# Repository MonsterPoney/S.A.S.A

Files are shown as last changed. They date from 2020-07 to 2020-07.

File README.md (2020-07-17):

# Projet S.A.S.A (Système Autonome de Stabilisation Active)
## Description
Le projet S.A.S.A. (Système Autonome de Stabilisation Active) a pour but de rendre les fusées amateures actuelles plus permissive en leurs appliquant une autonomie.
On passerait donc d’un système passif purement basé sur l’aérodynamique et dont l’allumage du/des moteur(s) scellerait quelconque action pour modifier la trajectoire a un système ‘intelligent’ pouvant effectuer des actions durant le vol permettant de stabiliser la trajectoire de la fusée.

## Les actions
Une stabilisation active sera amenée grâce à des empennages amovibles et un moteur à propulsion vectorielle.
Un seul moteur ne pouvant effectuer de correction de roulis, c’est donc les empennages qui auront ce rôle et le moteur effectuera les corrections de tangage et de lacet.

## Platine d'essai
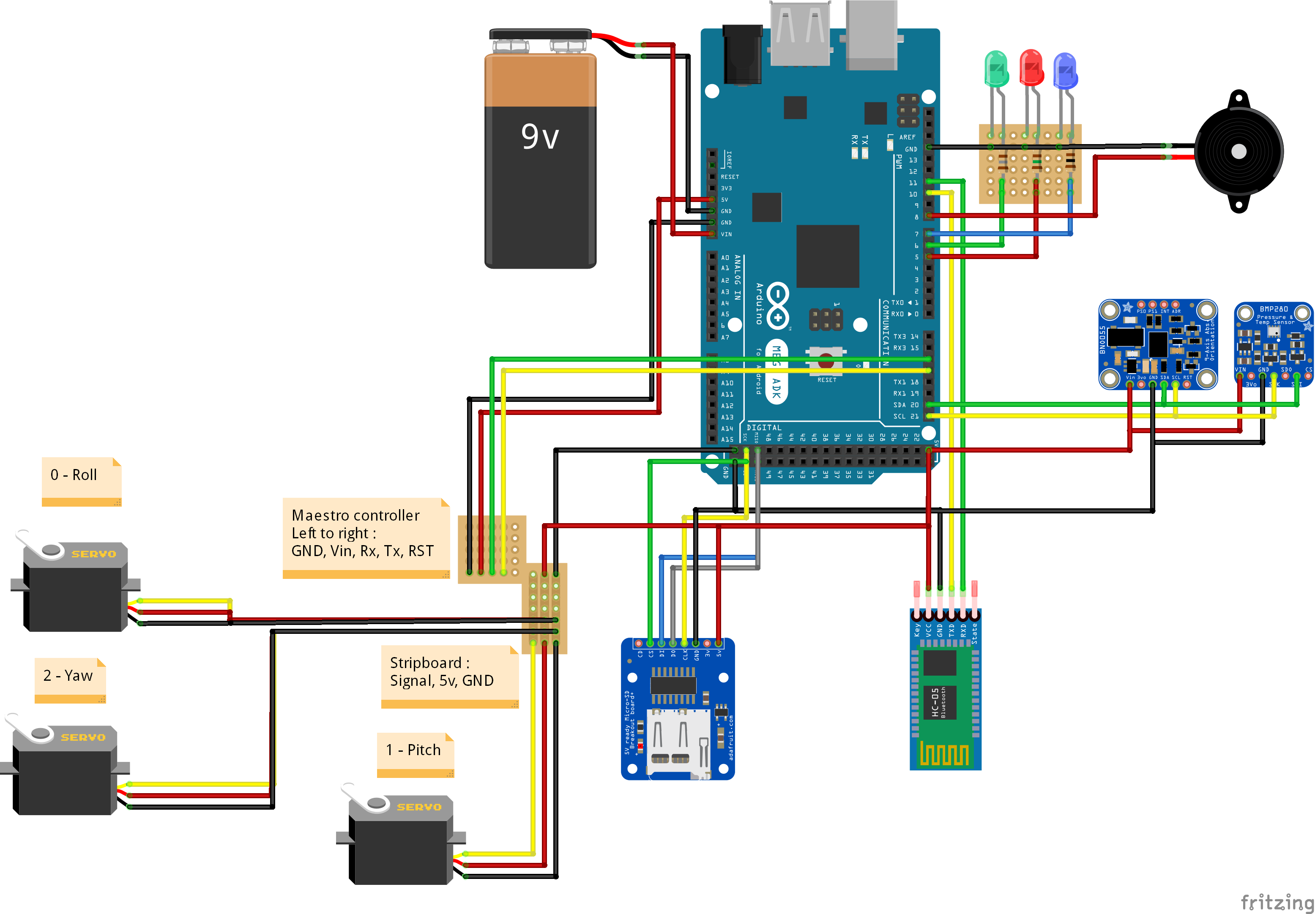
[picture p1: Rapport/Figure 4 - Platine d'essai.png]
alt platine d'essai


## Exemple de diagramme de temps
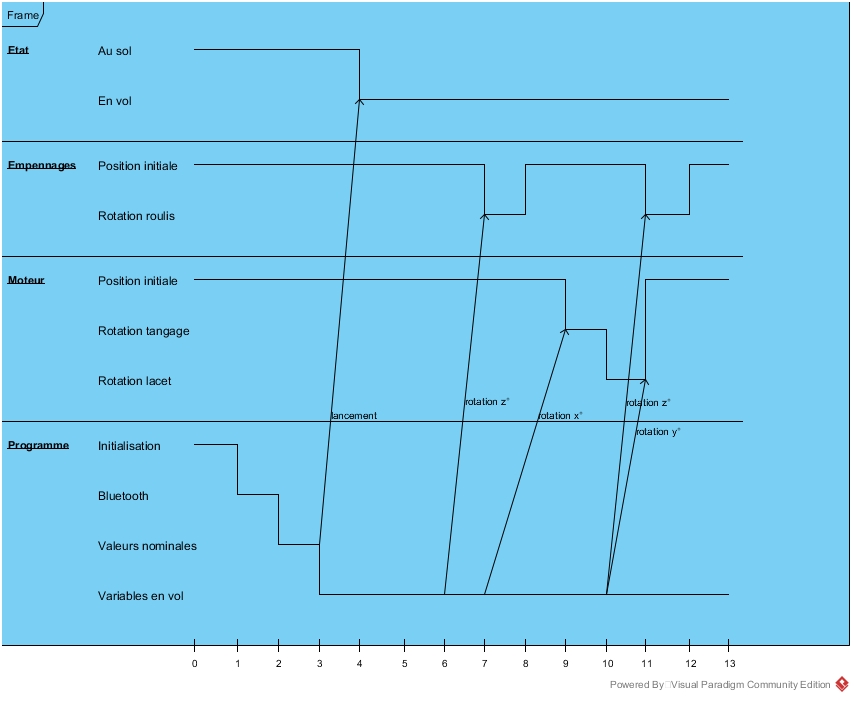
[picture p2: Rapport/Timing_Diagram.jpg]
alt diagramme de temps


## Organigramme de programmation initial
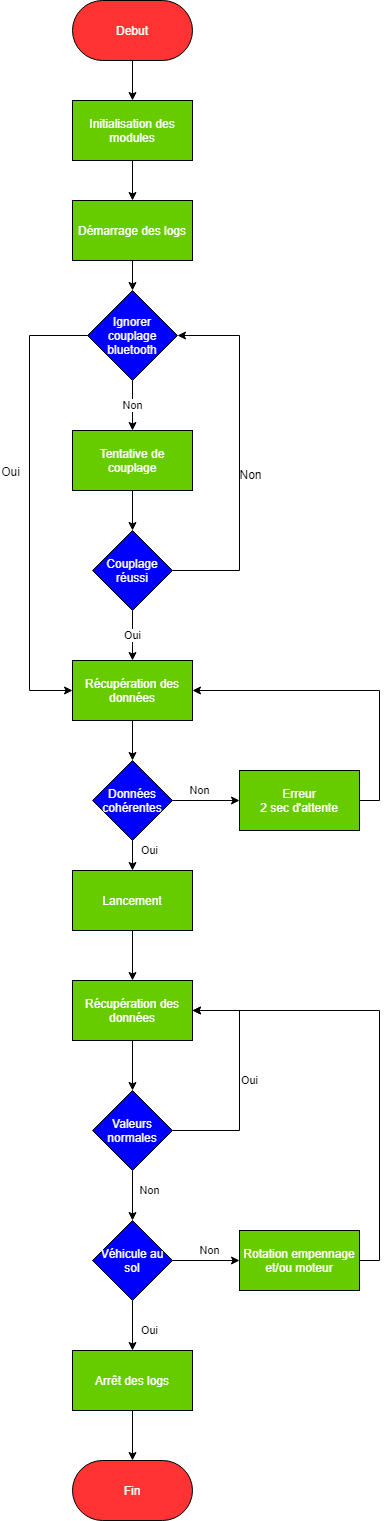
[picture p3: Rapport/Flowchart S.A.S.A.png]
alt Organigramme de programmation


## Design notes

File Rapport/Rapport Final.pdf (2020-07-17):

BOUR Valentin

Projet :
Système Autonome de
Stabilisation Active

# Rapport de projet

Introduction________________________________________________

Le projet S.A.S.A. (Système Autonome de Stabilisation Active) a pour but de rendre les fusées amateures actuelles plus permissive en leurs appliquant une autonomie.

Avec une stabilisation passive, la trajectoire ne peut être que légèrement parabolique ou rectiligne et aucune intervention ne peut être effectué pour modifier celle-ci une fois le ou les moteurs allumé(es).
On passerait donc d’un système passif purement basé sur l’aérodynamique et dont l’allumage du/des moteur(s) scellerait quelconque action pour modifier la trajectoire a un système ‘intelligent’ pouvant effectuer des actions durant le vol permettant de stabiliser la trajectoire de la fusée.

Le système n’utilisera pas de RCS ou d’actionneur gyroscopique à cause du coût et de la masse du dispositif, de plus des actionneurs gyroscopiques peuvent provoquer des vibrations et déstabilisé la fusée.

Les actions du dispositif_____________________________________

Une stabilisation active sera amenée grâce à des empennages amovibles et un moteur à propulsion vectorielle.
Un seul moteur ne pouvant effectuer de correction de roulis, c’est donc les empennages qui auront ce rôle et le moteur effectuera les corrections de tangage et de lacet.
Couplé à un ordinateur de bord, ce système peut alors devenir autonome.
Le système dispose également d’un module Bluetooth, si un appareil est appairé a celui-ci, il recevra les informations de pré-lancement tel que les valeurs de base du 9-DOF.
Le BNO055 (9-DOF) détectera le lancement, il s’en suivra donc l’activation complète du dispositif puis lorsque la phase d’atterrissage sera complète, l’accélération sera nulle, ce qui pourra arrêter le système.

Système Autonome de
Stabilisation Active

Les contraintes_____________________________________________

Le système doit être le plus léger possible afin d’avoir le moins d’impact sur les performances, il doit également être le plus petit possible.
Les mouvements des servos se doivent d’être précis et fluides afin d’avoir le moins de marge d’erreur et ne pas avoir d’accoups.
Aucune intervention humaine doit être nécessaire durant tout le procédé post-lancement.

Matériel___________________________________________________

1 Carte microcontrôleur
3 Servos
1 Contrôleur servos
1 Module bluetooth
1 Module SD
1 Capteur de pression
1 9-DOF

La carte microcontrôleur utilisé est un Arduino Mega 2560, l’utilisation d’une carte nano est possible pour réduire la taille et la masse.
Les servos sont des FS0403 de Feetech.
Le contrôleur servos est un Micro Maestro 6 canaux.
Le module bluetooth est un module HC-05.
Le module SD est une breakout SD avec régulateur 3.3v.
Le capteur de pression est le BMP280 et est utilisé pour obtenir l’altitude. La centrale inertielle 9-DOF est le BNO055.

Recherches________________________________________________

De nombreuses recherches ont été effectués durant l’accomplissement de ce projet à commencer par trouver le matériel nécessaire respectant les contraintes.

De conséquentes recherches sur la stabilité et l’aérodynamisme ont également été effectués, le système exercera son rôle dans un environnement contenant énormément de variables toutes cruciales, le moteur vectoriel et les empennages mobiles sont des acteurs importants et auront donc une incidence importante, ils ne doivent évidemment pas être négligés.

Système Autonome de
Stabilisation Active

Model 3D__________________________________________________

Le model 3D a été d’une grande aide, il a servi de référence pour le prototype et à aider à visualiser la mobilité de certains éléments ainsi que les contraintes mécaniques liés à l’espace.
Ce model a également été utile pour l’impression d’éléments.
Une animation d’assemblage a été réaliser, ce qui permet d’obtenir une perspective différente.
La modélisation a été faite sur Blender, un logiciel libre permettant également de faire de l’animation et du texturage.

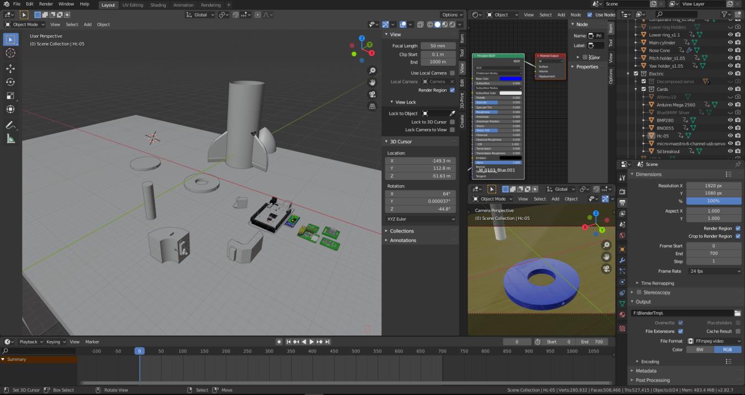
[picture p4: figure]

Figure 1 - Interface Blender

Le fichier compte une vingtaine d’objets constituant le système.

Système Autonome de
Stabilisation Active

Prototypage________________________________________________

Après la finalisation du model 3D, chaque pièce étant destinée à être imprimé doit généralement subir une transformation pour que celle-ci soit imprimable, surtout dans le cas où la pièce en question a été créé dans un logiciel non spécialisé dans la conception par ordinateur.

Les 2 principaux problèmes pouvant survenir :

- Overhangs : Les parties en surplomb, au-dessus d’un vide.
Ils doivent être éviter au maximum mais peuvent être résolu lors du passage dans un slicer en ajoutant des supports. Le temps d’impression sera donc augmenté.
- Non manifold geometry : Géométries ne pouvant exister dans le monde réel (faces à l’intérieur d’un objet, zones avec une épaisseur nulle, sommets ou arêtes déconnectées).

Après quelques essais d’impressions, un prototype en PLA a été réaliser, le slicer utiliser est Cura, il permet de paramétrer et de prévisualiser l’impression.

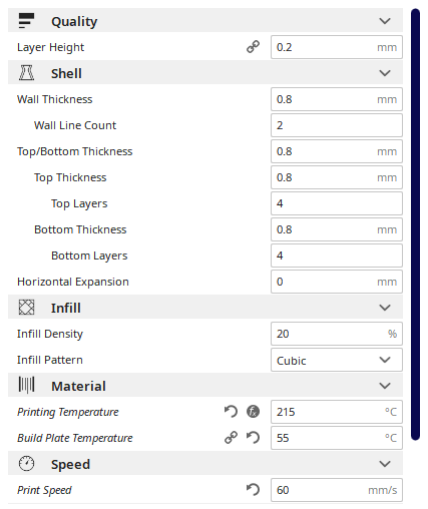
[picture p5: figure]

Figure 2 - Exemple de paramètres

Voici quelques-uns des paramètres les plus importants comme la hauteur de couche, l’épaisseur des parois, le pattern de remplissage ainsi que sa densité, la température et la vitesse d’impression.

Système Autonome de
Stabilisation Active

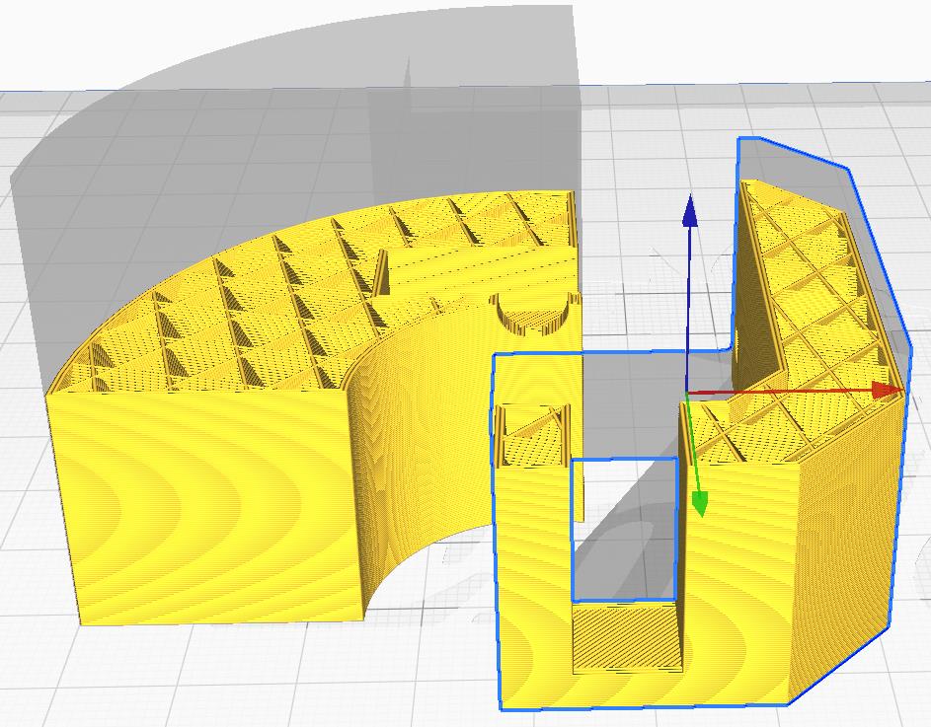
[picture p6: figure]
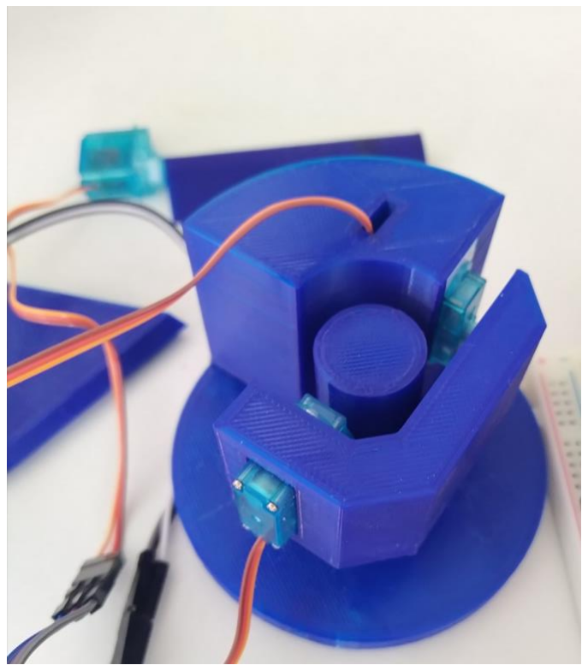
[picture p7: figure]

Figure 4 - Résultat d'impression

Après découpage, le logiciel estime un temps d’impression et une quantité de matériaux utilisé, une prévisualisation du parcours de la buse et également disponible.

Figure 3 - Visualisation du découpage

Système Autonome de
Stabilisation Active

Assemblage électronique____________________________________

Le montage électronique a été réaliser sans trop de difficultés grâce à l’utilisation d’une carte Arduino facilitant grandement la gestion des entrées / sorties du microprocesseur. Possédant déjà un Arduino Mega, celle-ci a été utilisée mais une Nano est suffisante pour ce système et est plus petite et plus légère.
Des ajustements peuvent être réalisés mais aucun changement majeur ne sera effectué. Un schéma du système a été réalisé.

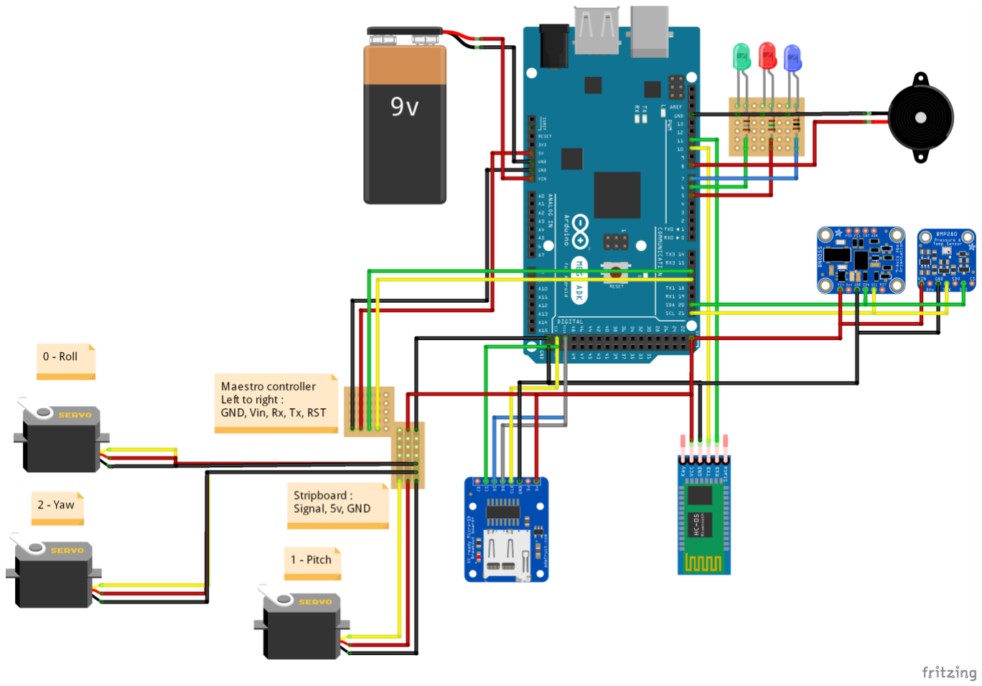
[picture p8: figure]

Figure 5 - Platine d'essai

Système Autonome de
Stabilisation Active

La représentation graphique a été faite sur Fritzing, le contrôleur servos n’étant pas disponible, il a été représenter par deux cartes à matrice et annoté en conséquence. Le module SD est visible en bas à droite des servos, à côté de celui-ci, le module Bluetooth.
A droite de l’écran se trouve le BNO055 et le BMP280.

Programmation_____________________________________________

Un souci matériel a causé un problème de communication avec le contrôleur de servos empêchant donc toute interaction avec ceux-ci, ce problème a été résolu.

Les acquisitions de données du capteur initial ont montré que celui-ci avait besoin d’être calibré pour fonctionner de correctement, la complexité d’utilisation de ce capteur m’a donc freiné, c’est pour cette raison que je l’ai remplacé par deux autres capteurs.

Un module Bluetooth (HC-05) envoie les données de pré-lancement a l’appareil appairé, pour des raisons d’intégrité le système n’est pas pilotable à distance, le module ne traite donc aucunes données et ne réalise que des envoie.

Une carte microSD enregistre constamment l’état du programme et des capteurs, ce qui permet une persistance de données et un traçabilité d’éventuelles erreurs.
Le fichier résultant de cet enregistrement est un simple fichier texte, cependant, sa mise en page permet d’exploiter ce document dans un tableur afin d’en faire une analyse (graphique, calcul etc…).

Les valeurs d’axes fourni par le 9-DOF possèdent une échelle différente des servos, j’effectue donc une conversion afin de les rendre compréhensible par ceux-ci.

Système Autonome de
Stabilisation Active

Simulation_________________________________________________

Les simulateurs ne peuvent pas prendre en compte une stabilisation active, les simulations ont donc été utilisées pour voir l’impact du dispositif sur la fusée. Le principal outil utilisé est OpenRocket, il permet une création et une visualisation en 2D de la fusée.
Des paramètres environnementaux peuvent être spécifiés.

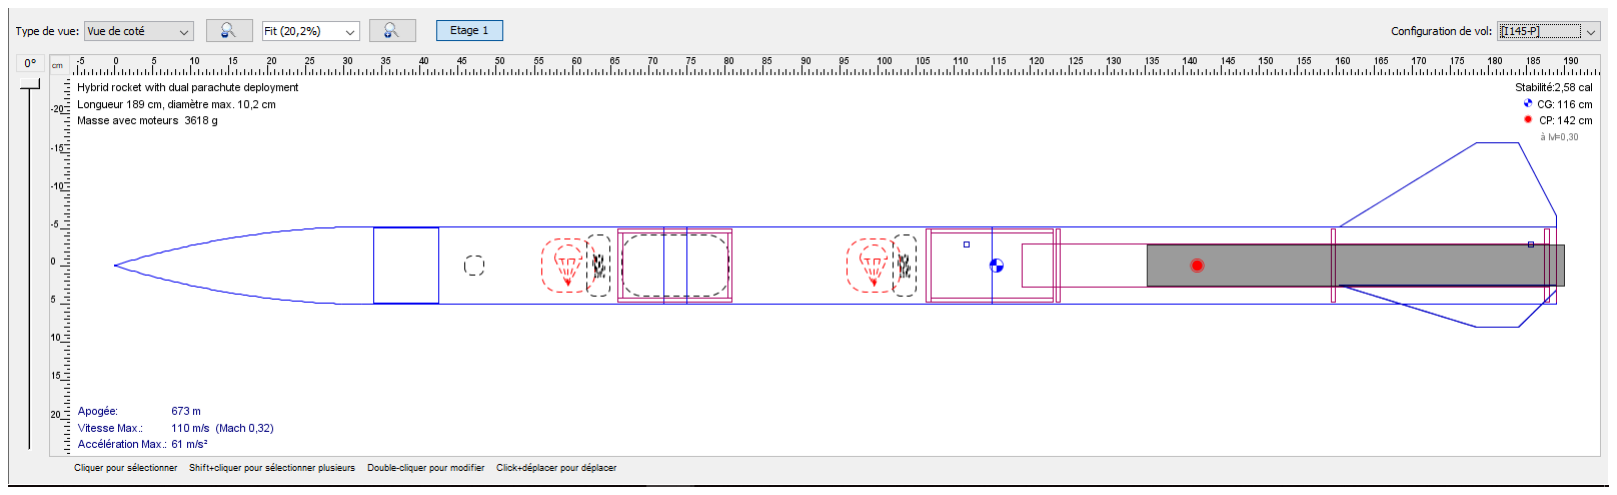
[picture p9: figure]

Figure 6 - Visuel de conception

Deux simulations ont été effectuée :
La première avec la stabilisation passive, donc sans système
La seconde avec la stabilisation active
La différence se traduit par la diminution des turbulences et perturbations et en ajoutant une masse simulant celle du système.

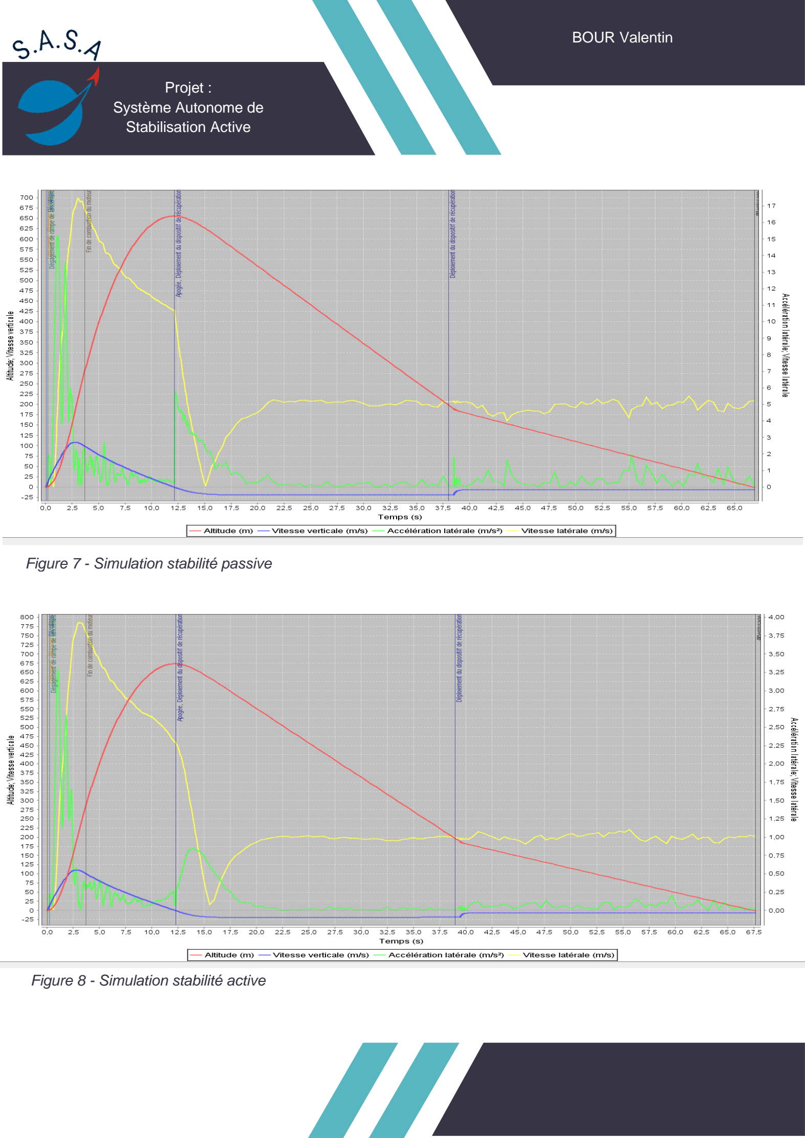
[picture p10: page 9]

Système Autonome de
Stabilisation Active

Figure 7 - Simulation stabilité passive

Figure 8 - Simulation stabilité active

Système Autonome de
Stabilisation Active

Nous pouvons voir que la simulation avec stabilité active a une accélération latérale moindre car le système compense les aléas environnementaux.
De ce fait son altitude max (apogée) est plus grande, 674m contre 657m sur le 1e graphique.
Donc la masse que représente le dispositif est compensée par son action, une différence de 2.58% est visible sur l’apogée.

Ce pourcentage peut sembler dérisoire, en effet, appliqué à une apogée initiale de 10m, le système n’est que peu avantageux.
Cependant, certaines fusées expérimentales tel que la fusée « Elyjia » lancée en 2007 atteignent une altitude supérieure à 1km (1700m dans le cas d’Elyjia).

Code couleur est sonore du système___________________________

- Led bleu, vert et rouge : Standby
- Led bleu, vert, rouge et bip sonore discontinue : Standby post atterrissage / amerrissage
- 2 courts bips sonores : Carte SD non détectée
- Led rouge et 3 longs bips sonores : Erreur critique (BNO055 ou BMP280 non détectée)
- 1 long bip sonore : Acquisition et mise en place des valeurs par défaut terminé

Glossaire__________________________________________________

- Axes aérodynamiques :
- Roulis : Rotation autour de l’axe longitudinale de la fusée
- Tangage : Rotation autour de l’axe latéral
- Lacet : Rotation autour de l’axe vertical
- BMP280 : Capteur de pression / Altimètre
- BNO055 / 9-DOF : 9 Degrees Of Freedom, 3 axes données par 3 capteurs, un gyroscope, un accéléromètre et un magnétomètre.
- RCS : Reaction Control System

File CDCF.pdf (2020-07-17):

BOUR Valentin

Projet :
Système Autonome de
Stabilisation Active
BOUR Valentin | Msc.1

# Cahier des Charges Fonctionnel

Projet S.A.S.A.

Présentation générale du besoin

Situation actuelle
Du fait de leurs courte durée de fonctionnement et de leurs apogée faible, les micro-fusées (propulseur de type A,B et C) ne disposent que d’une stabilisation passive à l’aide d’empennages fixes.

Cependant,les mini-fusées ainsi que les fusées à cluster ou à étages peuvent atteindre une hauteur bien plus élevé et donc un fonctionnement plus long.

Avec une stabilisation passive, la trajectoire ne peut être que légèrement parabolique ou rectiligne et aucune intervention ne peut être effectué pour modifier celle-ci une fois le ou les moteurs allumé(es).

Solutions déjà explorées, exclues
Une solution de RCS (Reaction Control System) est exclu du fait de son coût et de la masse du dispositif.

Les actionneurs gyroscopiques sont exclus à cause de leurs faible efficacité dans l’atmosphère et des vibrations provoquée par ce système qui pourrait avoir l’effet inverse et déstabilisé la fusée.

Résultats et changements attendu

Une stabilisation active peut être amené grâce à des empennages movibles et un moteur à propulsion vectorielle.
Un seul moteur ne pouvant effectuer de correction de roulis, c’est donc les empennages qui auront ce rôle et le moteur effectuera les corrections de tangage et de lacet.
Couplé à un ordinateur de bord, ce système peut alors devenir autonome.

Le système peut également être doté d’un module bluetooth afin d’envoyer des informations pré lancement à une application Android pour contrôler la cohérence des valeurs avant le lancement.

Système Autonome de
Stabilisation Active

Expression détaillée du besoin

Phases du cycle de vie et leur environnement
Voir “Diagramme de temps” en Annexes :
Ce diagramme représente l’avancement du programme et les différents cas possibles dans le temps, en premier lieu une initialisation des modules, l'appairage bluetooth et l’obtention des valeurs nominale pré-lancement.
Une fois ces valeurs acquise, le lancement s’effectue et des données sont obtenues tout au long du vol, l'interprétation de ses données peuvent entraîner une rotation des empennages ou du moteur.

Voir “Diagramme de programmation” en Annexes :
Représentation graphique du déroulement du programme, de l’initialisation jusqu’à l'arrêt du véhicule en comprenant les “routes” alternatives du programme.

Liste des fonctions/services attendus
Quelles fonctions à assurer ?
- Compenser les aléas atmosphériques
- Maintenir sa trajectoire
- Envoyer les valeurs via Bluetooth

Le moteur doit être capable de pivoter sur 2 axes, une rotation de 10° doit être possible. Les empennages doivent également être capable de pivoter.
Les données doivent être acquise en temps réel.

Caractérisation de chaque fonction

N° | Intitulé | Condition
F1 | Acquisition de données | Disponibilité capteur AltIMU
F2 | Rotation des empennages | Valeur du capteur AltIMU
F2 | Rotation du moteur sur l’axe X | Valeur du capteur AltIMU
F3 | Rotation du moteur sur l’axe Y | Valeur du capteur AltIMU
F5 | Enregistrement des données | Disponibilité carte SD
F6 | Envoie des données via Bluetooth | Appareil appairé

Système Autonome de
Stabilisation Active

Annexes

Diagramme de temps

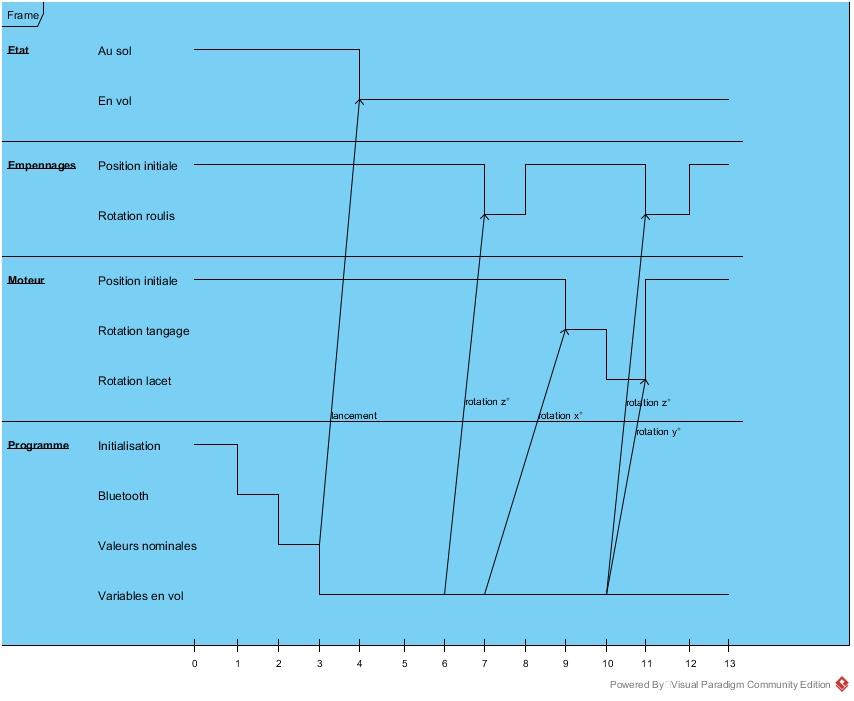
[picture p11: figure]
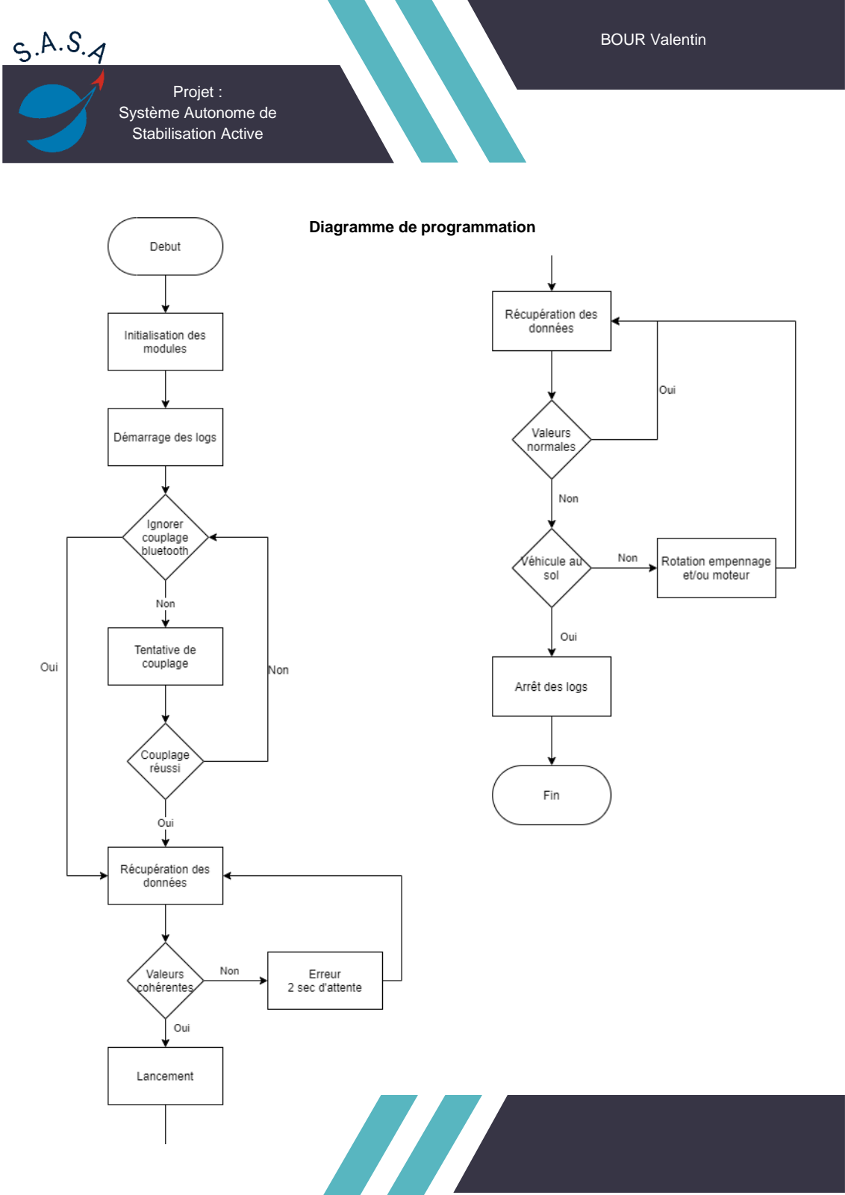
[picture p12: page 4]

Système Autonome de
Stabilisation Active

Diagramme de programmation

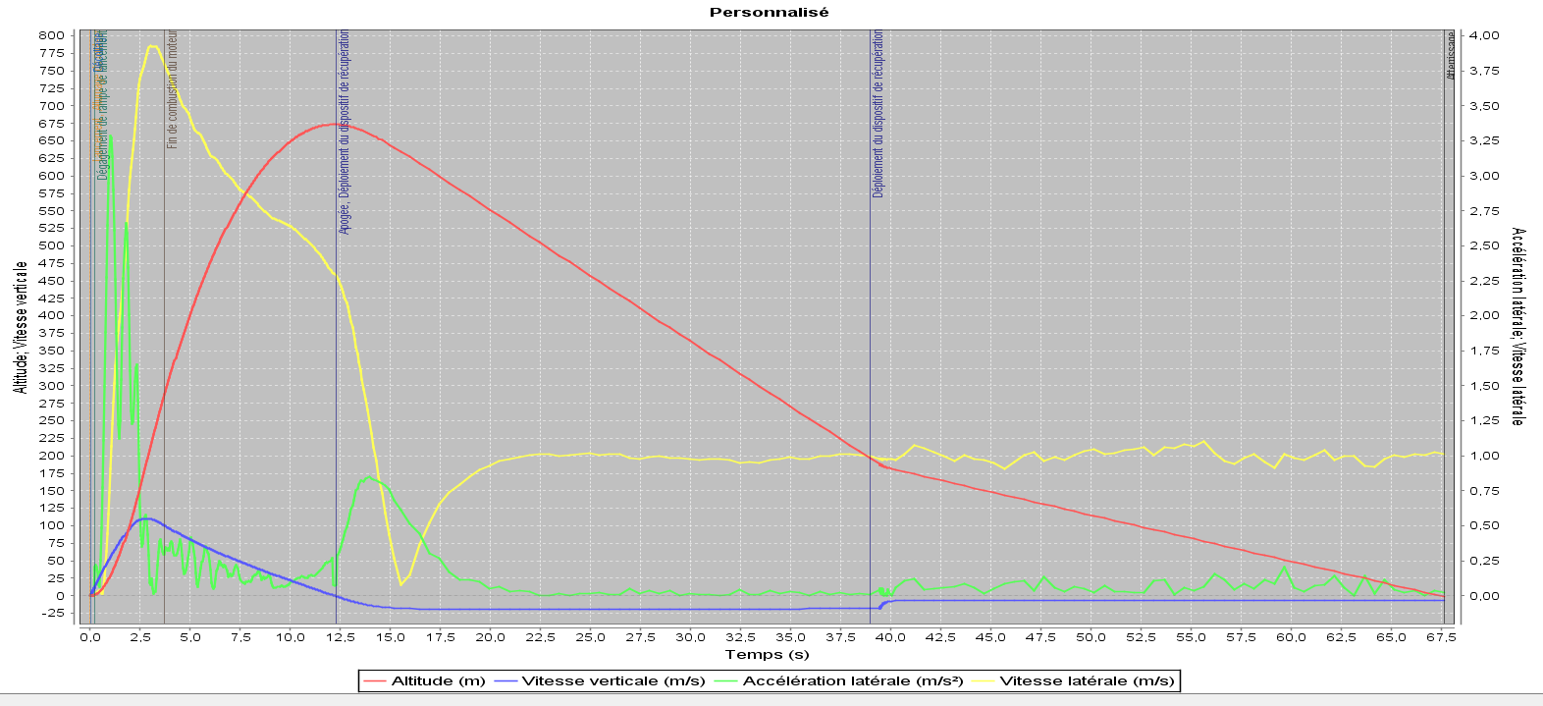
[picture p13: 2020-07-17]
Rapport/Figure 7 - Simulation stabilité active.PNG

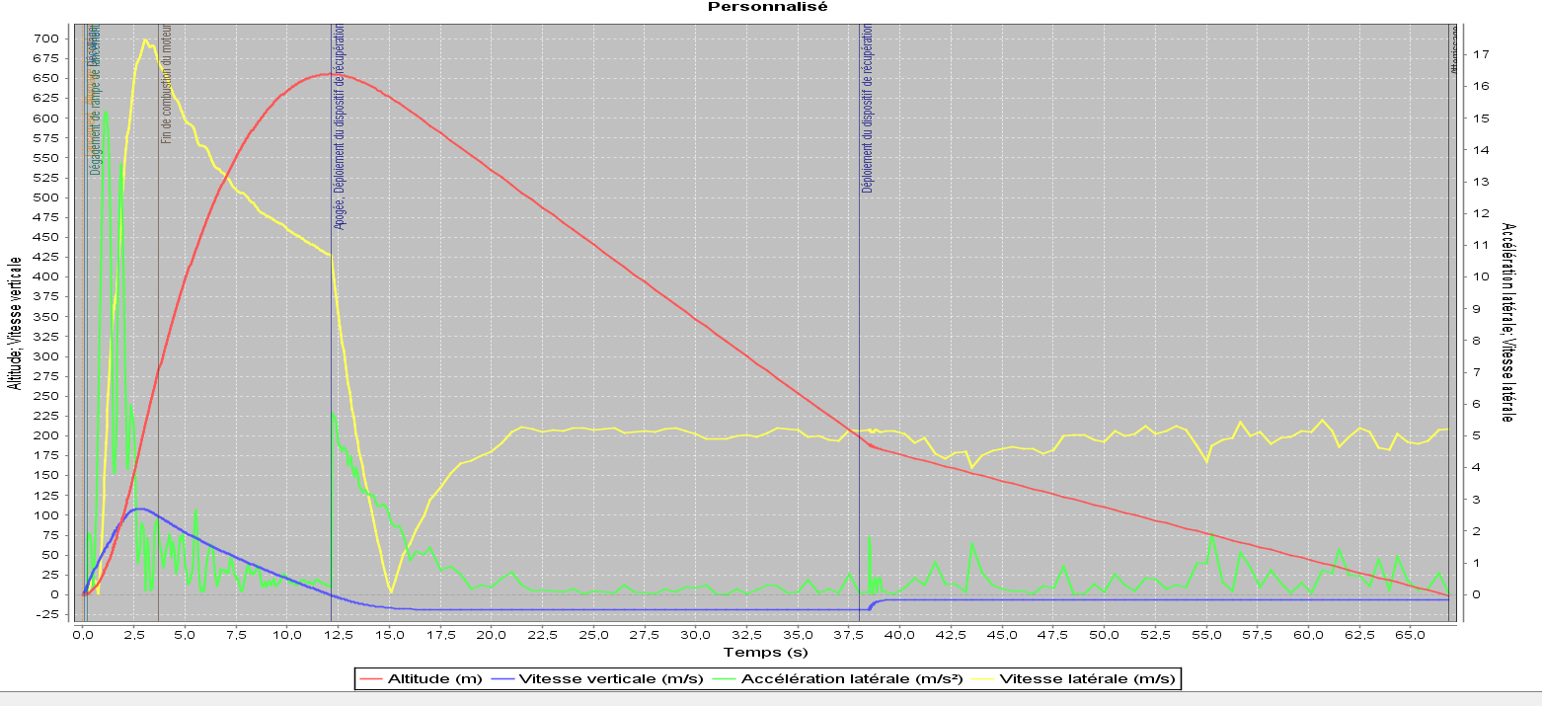
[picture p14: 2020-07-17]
Rapport/Figure 6 - Simulation stabilité passive.PNG

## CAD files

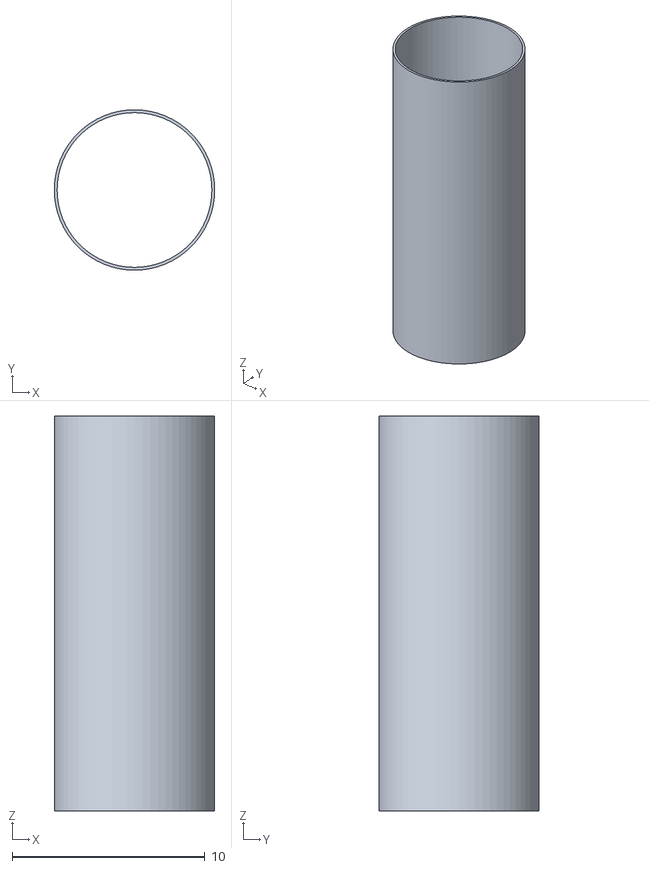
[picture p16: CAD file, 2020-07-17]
3D/Prints/Main_cylinder.stl
8.32 x 8.32 x 20.5

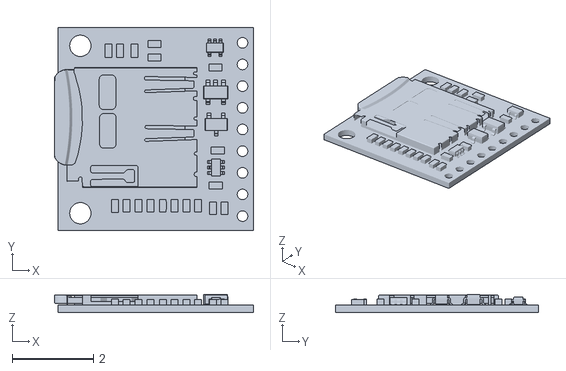
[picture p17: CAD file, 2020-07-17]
3D/res/SD breakout.stl
4.89 x 4.98 x 0.452

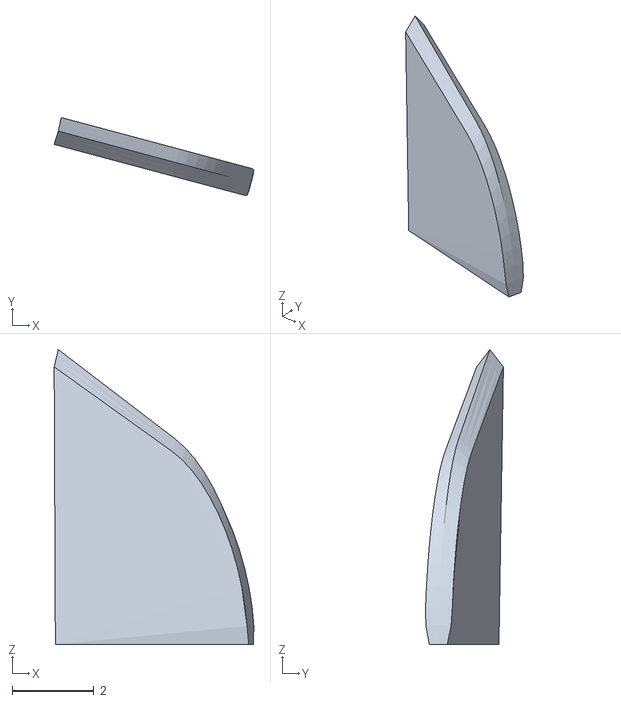
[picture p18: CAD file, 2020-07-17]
3D/Prints/Wing.stl
4.87 x 1.90 x 7.20

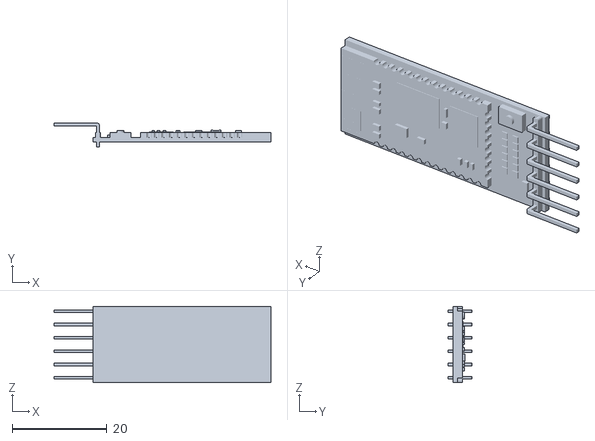
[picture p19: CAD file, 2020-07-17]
3D/res/hc-05.stl
45.8 x 5.00 x 16.1

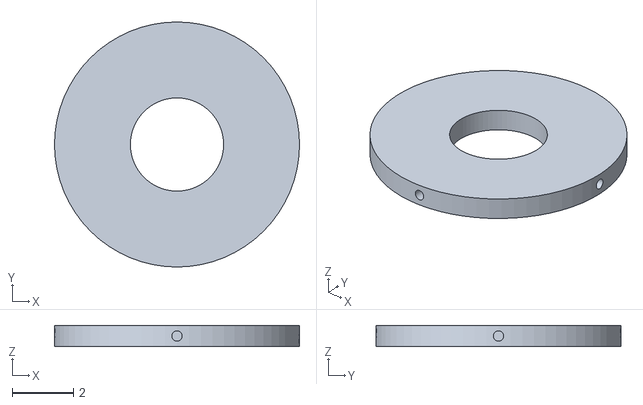
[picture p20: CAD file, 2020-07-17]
3D/Prints/Lower_ring.stl
8.00 x 8.00 x 0.7

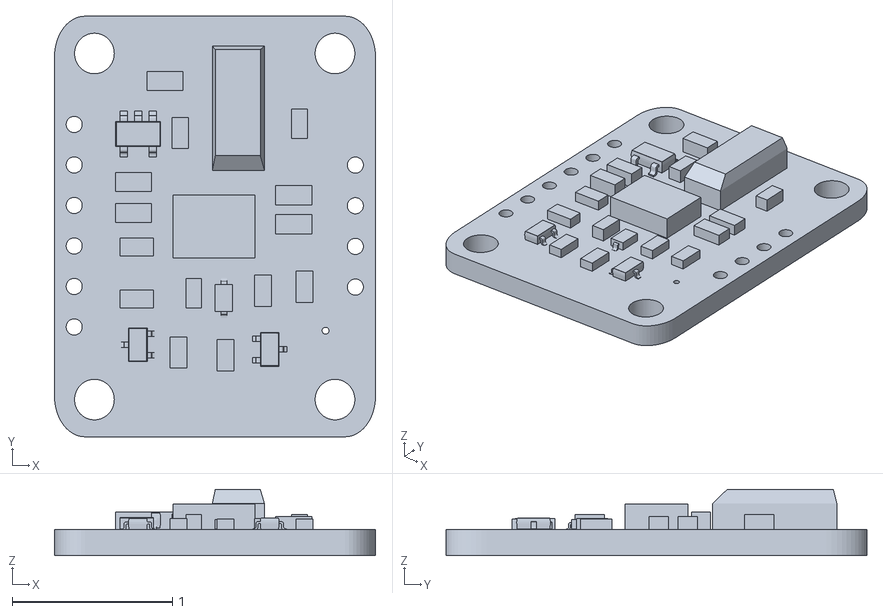
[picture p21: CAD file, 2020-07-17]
3D/res/BNO055.stl
2.00 x 2.63 x 0.415

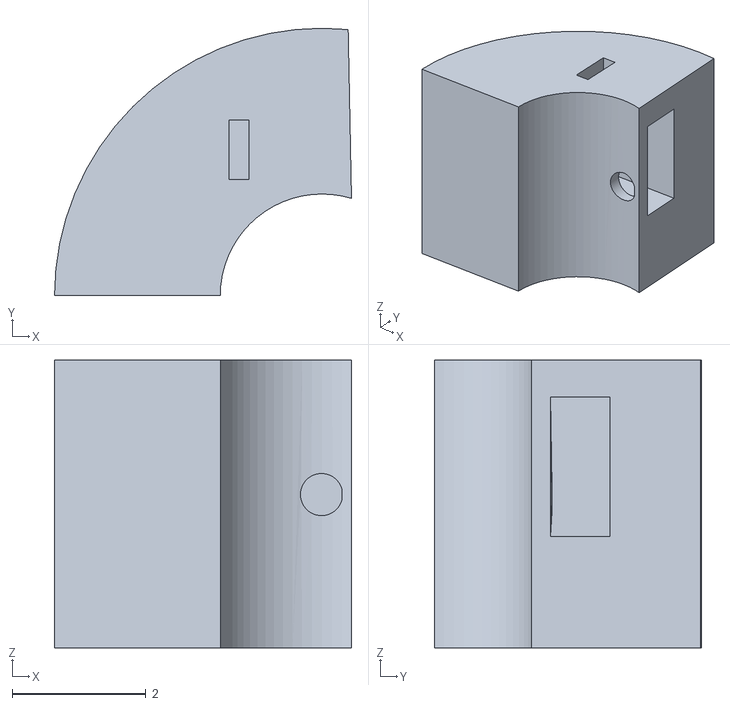
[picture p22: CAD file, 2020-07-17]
3D/Prints/Yaw_holder.stl
4.44 x 4.00 x 4.31

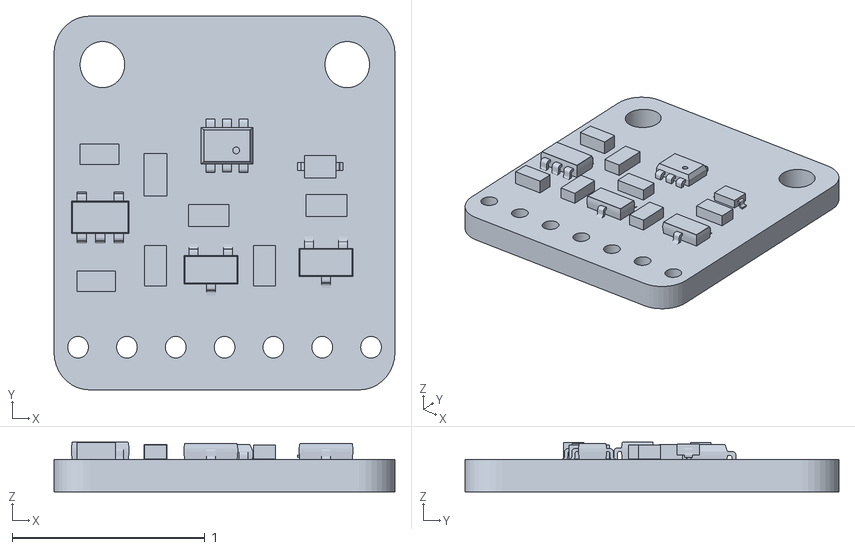
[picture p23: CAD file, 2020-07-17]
3D/res/bmp280.stl
1.77 x 1.94 x 0.259

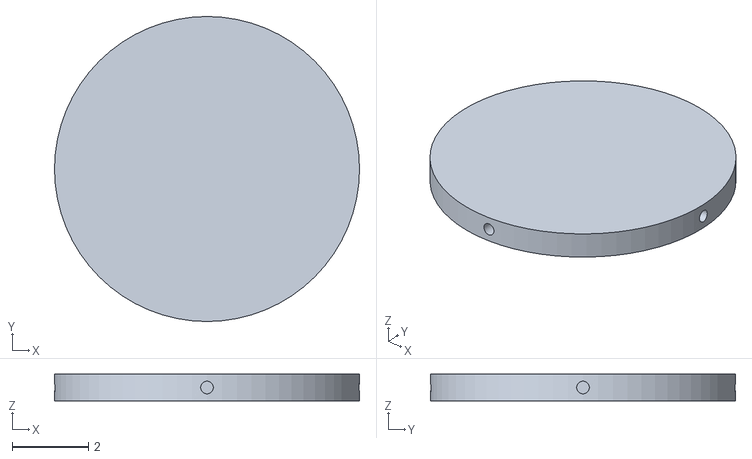
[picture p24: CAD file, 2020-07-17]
3D/Prints/Componant_ring.stl
8.00 x 8.00 x 0.7

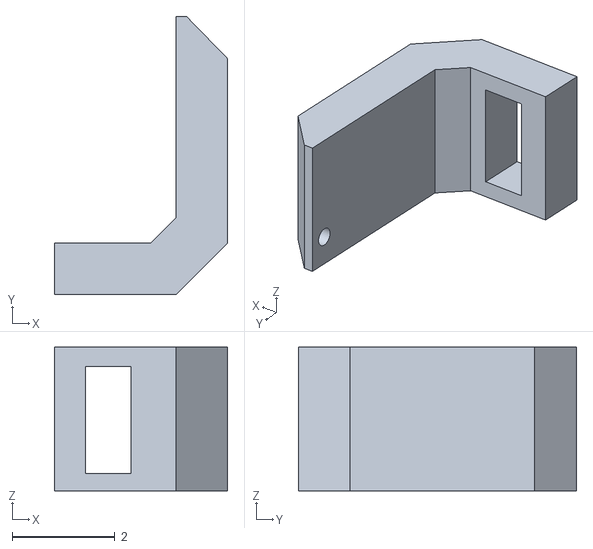
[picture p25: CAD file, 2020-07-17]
3D/Prints/Pitch_holder.stl
3.37 x 5.42 x 2.80

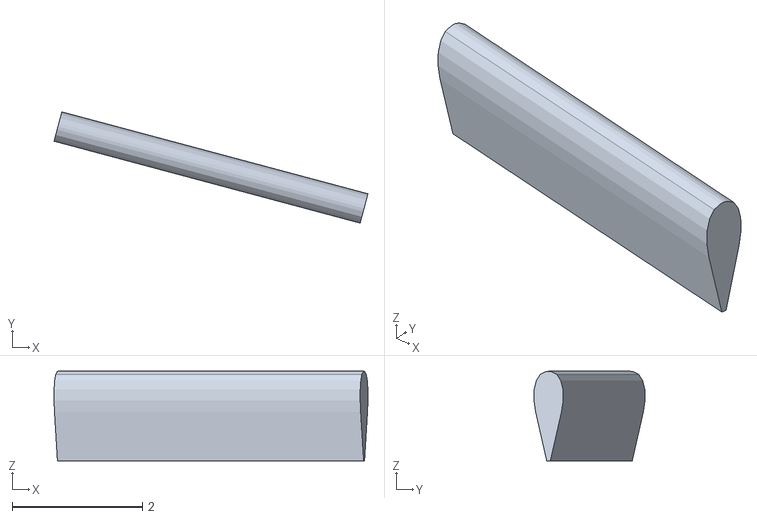
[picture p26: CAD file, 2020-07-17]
3D/Prints/Wing_flap.stl
4.83 x 1.71 x 1.38

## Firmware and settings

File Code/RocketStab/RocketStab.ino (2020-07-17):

#include <SD.h>
#define SDcard 53
File logFile;
bool cardPresent = true;
bool isLaunched = false;
int nullAccel = 0;
const String logHeader = "temps;orientationX;orientationY;orientationZ;accelerationX;accelerationY;accelerationZ;altitude";
String fileName = "LOG";

// Bluetooth
#include <SoftwareSerial.h>
#define blueTx 11
#define blueRx 10
SoftwareSerial bluetooth(blueRx,blueTx);

#include <Wire.h>
#include <SPI.h>

// BNO055
#include <Adafruit_BNO055.h>
#include <utility/imumaths.h>
//                                   id, address
Adafruit_BNO055 bno = Adafruit_BNO055(55, 0x28);

//BMP280
#include <Adafruit_BMP280.h>
float seaLevelhPa = 1013;

//Maestro
#include <PololuMaestro.h>
#define maestroSerial Serial2
#define chanROLL 0
#define chanYAW 2
#define chanPITCH 1
const int midPITCH = 5940;
const int minPITCH = 5520;
const int maxPITCH = 6360;
const int rangePITCH = (maxPITCH-minPITCH)/2;
double Ytarget=0;
const int midYAW = 5940;
const int minYAW = 5400;
const int maxYAW = 6520;
const int rangeYAW = (maxYAW-minYAW)/2;
double Ztarget=0;
const int midROLL = 5960;
const int minROLL = 4992;
const int maxROLL = 6976;
const int rangeROLL = (maxROLL-minROLL)/2;
double Xtarget=0;
// sensibility in degree
const int sensibility = 1;
MicroMaestro maestro(maestroSerial);

#define chipSelect 53
#define ledR 5
#define ledG 6
#define ledB 7
#define buzzer 12

#include <Adafruit_Sensor.h>
#define BMP_SCK  (13)
#define BMP_MISO (12)
#define BMP_MOSI (11)
#define BMP_CS   (10)
Adafruit_BMP280 bmp;

//BMP280 var
float bmp_temp, bmp_pressure, bmp_altit;

int iRef = 0;
double ref_orientX = 0, ref_orientY = 0, ref_orientZ = 0;

int iRef2 = 0;
double ref_accelX = 0, ref_accelY = 0, ref_accelZ = 0;


sensors_event_t orientData, accelData;

void beep(String _type = "SHORT", int _iteration = 1, int _delay = 100){
  for(int f=0;f++;f<_iteration){
    digitalWrite(buzzer,HIGH);
    delay((_type == "LONG") ? 300 : 100);
    digitalWrite(buzzer,LOW);
    delay(_delay);
  }
}

void setup() {
  Serial.begin(9600);

  Wire.begin();

  pinMode(ledR,OUTPUT);
  pinMode(ledG,OUTPUT);
  pinMode(ledB,OUTPUT);
  pinMode(buzzer,OUTPUT);
  pinMode(blueRx, INPUT);
  pinMode(blueTx, OUTPUT);
  
  bluetooth.begin(9600);
  delay(500);

  bluetooth.print("SD card test \r\n");
  pinMode(SDcard,OUTPUT);
  if(!SD.begin(SDcard)){ 
    beep("SHORT",2);
    bluetooth.print("SD card not detected \r\n");
    cardPresent = false;
  }else{
    bluetooth.print("SD card OK");
    for(int i = 0;i<200;i++){
      if(!SD.exists(fileName + (i)+".txt")){
        fileName = fileName + i + ".txt";
        bluetooth.print("fileName : " + fileName + "\r\n");
        logFile = SD.open(fileName,FILE_WRITE);
        logFile.println("I (" + getTimestamp() + ") : log start");
        break;
      }
    }
  }

  bluetooth.print("BMP280 test\r\n");
  if (!bmp.begin()) {
    digitalWrite(ledR,HIGH);
    beep("LONG",3);
    bluetooth.print("Could not find a valid BMP280 sensor, check wiring!\r\n");
    if(cardPresent) logFile.println("E : BMP280 sensor not find");
    while (1);
  }else{
    bluetooth.print("BMP280 ok\r\n");
    if(cardPresent)logFile.println("I : BMP280 sensor operational");
  }

  bluetooth.print("Orientation Sensor Test\r\n");
  if (!bno.begin()){
    digitalWrite(ledR,HIGH);
    beep("LONG",3);
    bluetooth.print("No BNO055 detected... Check your wiring or I2C address!\r\n");
    if(cardPresent) logFile.println("E : BNO055 sensor not found");
    while (1);
  }else
    if(cardPresent)logFile.println("I : BNO055 sensor operational");

  adafruit_bno055_offsets_t Calibration;
  Calibration.accel_offset_x = -32;
  Calibration.accel_offset_y = -87;
  Calibration.accel_offset_z = -46;

  Calibration.mag_offset_x = -152;
  Calibration.mag_offset_y = -545;
  Calibration.mag_offset_z = 441;

  Calibration.gyro_offset_x = 0;
  Calibration.gyro_offset_y = -2;
  Calibration.gyro_offset_z = -1;

  Calibration.accel_radius = 1000;
  Calibration.mag_radius = 683;

  bno.setSensorOffsets(Calibration);
  /* Use external crystal for better accuracy */
  bno.setExtCrystalUse(true);
  if(cardPresent)logFile.println("I : BNO055 calibration imported");
  bluetooth.print("BNO055 calibration imported\r\n");

  maestroSerial.begin(9600);
  maestro.setAcceleration(1,0);
  maestro.setAcceleration(2,0);
  maestro.setSpeed(1,0);
  maestro.setSpeed(2,0);
  maestro.setTarget(chanPITCH,midPITCH);
  maestro.setTarget(chanYAW,midYAW);
  maestro.setTarget(chanROLL,midROLL);

   /* Default settings from datasheet. */
  bmp.setSampling(Adafruit_BMP280::MODE_NORMAL,     /* Operating Mode. */
          Adafruit_BMP280::SAMPLING_X2,     /* Temp. oversampling */
          Adafruit_BMP280::SAMPLING_X16,    /* Pressure oversampling */
          Adafruit_BMP280::FILTER_X16,      /* Filtering. */
          Adafruit_BMP280::STANDBY_MS_500); /* Standby time. */


  digitalWrite(ledR,HIGH);
  delay(300);
  digitalWrite(ledG,HIGH);
  delay(300);
  digitalWrite(ledB,HIGH);
  delay(300);

  logFile.println("BNO temp : " + String(bno.getTemp()) + "BMP temp : " + String(bmp.readTemperature()));
  bluetooth.print("Setup finish\r\n");

   bno.getEvent(&orientData,Adafruit_BNO055::VECTOR_EULER);
   bno.getEvent(&accelData,Adafruit_BNO055::VECTOR_ACCELEROMETER);
// Define orientation default values
    while(iRef < 10){
      ref_orientX = ref_orientX + orientData.orientation.x;
      ref_orientY = ref_orientY + orientData.orientation.y;
      ref_orientZ = ref_orientZ + orientData.orientation.z;
      iRef++;
      delay(200);
      if(iRef >= 10){
        ref_orientX = ref_orientX/10;
        ref_orientY = ref_orientY/10;
        ref_orientZ = ref_orientZ/10;
        bluetooth.print("FINAL orientation: " + String(ref_orientX) + "y: " + String(ref_orientY) + "z: " + String(ref_orientZ) + "\r\n");
      }
    }
// Define acceleration default values
    while(iRef2 < 10){
      ref_accelX = ref_accelX + accelData.orientation.x;
      ref_accelY = ref_accelY + accelData.orientation.y;
      ref_accelZ = ref_accelZ + accelData.orientation.z;
      iRef2++;
      delay(200);
      if(iRef2 >= 10){
        Serial.println("Acceleration -> x: " + String(ref_accelX) + "y: " + String(ref_accelY) + "z: " + String(ref_accelZ));
        ref_accelX = ref_accelX/10;
        ref_accelY = ref_accelY/10;
        ref_accelZ = ref_accelZ/10;
        bluetooth.print("FINAL acceleration: " + String(ref_accelX) + "y: " + String(ref_accelY) + "z: " + String(ref_accelZ) + "\r\n");
      }
    }
  
  if(cardPresent)logFile.println("I : Setup finish \r\n"+ logHeader);
  if(cardPresent)logFile.flush();
  
  beep("SHORT",1);
  beep("LONG",1);
  ledsState(false);
}

void loop() {
  uint8_t system, gyro, accel, mag;
  system = gyro = accel = mag = 0;
  bno.getCalibration(&system, &gyro, &accel, &mag);
  
  if (system > 1){
    bno.getEvent(&orientData,Adafruit_BNO055::VECTOR_EULER);
    bno.getEvent(&accelData,Adafruit_BNO055::VECTOR_ACCELEROMETER);
  
    double orientX = orientData.orientation.x - ref_orientX;
    double orientY = orientData.orientation.y - ref_orientY;
    double orientZ = orientData.orientation.z - ref_orientZ;
  
    double accelX = accelData.orientation.x - ref_accelX;
    double accelY = accelData.orientation.y - ref_accelY;
    double accelZ = accelData.orientation.z - ref_accelZ;

    if (accelZ > 1){
      isLaunched = true;
      ledsState(false);
    }
    if (isLaunched){
      
      if (abs(accelZ) <0.5)
        nullAccel++;
      else
        nullAccel = 0;
      if (nullAccel >= 10)
        safeState();
        
      logFile.print(getTimestamp() + String(orientX) + ';' + String(orientY) + ';' + String(orientZ) + ';' + String(accelX) + ';' + String(accelY) + ';' + String(accelZ) + ';');

      if(orientY > 2){
        if(orientY>=sensibility)orientY=sensibility;
        // angle % on 45° || (range * R%)/100 || add min range
        Ytarget = (rangePITCH*((orientY*100)/sensibility))/100+midPITCH;
        maestro.setTarget(chanPITCH,Ytarget);
      }else if(orientY < -2){
        orientY = abs(orientY);
        if(orientY>=sensibility)orientY=sensibility;
        // angle % on 45° || (range * R%)/100 || add min range
        Ytarget = abs((rangePITCH*((orientY*100)/sensibility))/100-midPITCH);
        maestro.setTarget(chanPITCH,Ytarget);
      }else{
        maestro.setTarget(chanPITCH,midPITCH);
      }
      if(orientZ > 2){
        if(orientZ>=sensibility)orientZ=sensibility;
        Ztarget = (rangeYAW*((orientZ*100)/sensibility))/100+midYAW;
        maestro.setTarget(chanYAW,Ztarget);
      }else if (orientZ<-2){
        orientZ=abs(orientZ);
       if(orientZ>=sensibility)orientZ=sensibility;
        Ztarget = abs((rangeYAW*((orientZ*100)/sensibility))/100-midYAW);
        maestro.setTarget(chanYAW,Ztarget);
      }else{
        maestro.setTarget(chanYAW,midYAW);
      }
      if(orientX>2){
        if(orientX>=sensibility)orientX=sensibility;
        Xtarget = (rangeROLL*((orientX*100)/sensibility)/100+midROLL);
        maestro.setTarget(chanROLL,Xtarget);
      }else if (orientX<-2){
        orientX=abs(orientX);
        if(orientX>=sensibility)orientX=sensibility;
        Xtarget = abs(rangeROLL*((orientX*100)/sensibility)/100-midROLL);
        maestro.setTarget(chanROLL,Xtarget);
      }else{
        maestro.setTarget(chanROLL,midROLL);
      }

      logFile.println(String(bmp.readAltitude(seaLevelhPa)) + ";");
    
      logFile.flush();
      delay(25);
    }
  }else{
    Serial.println(F("W : Bad calibration, data dumped"));
    if(cardPresent)logFile.println("Bad;calibration;,;data;dumped");
  }
}

String getTimestamp(){
  String t_min = (String) (micros()/60000000);
  String t_sec =(String) (micros()%60000000/1000000);
  String t_ms =(String) (micros()%1000000/1000);
  return t_min + ':' + t_sec + '.' + t_ms + ';';
}

void ledsState(bool _on){
  if(_on){
    digitalWrite(ledR,HIGH);
    digitalWrite(ledG,HIGH);
    digitalWrite(ledB,HIGH);
  }else{
    digitalWrite(ledR,LOW);
    digitalWrite(ledG,LOW);
    digitalWrite(ledB,LOW);
  }
}

void safeState(){
  ledsState(true);
  
  while (1){
    digitalWrite(buzzer,HIGH);
    delay(200);
    digitalWrite(buzzer,LOW);
    delay(100);
    digitalWrite(buzzer,HIGH);
    delay(200);
    digitalWrite(buzzer,LOW);
    delay(2000);
  }
}
